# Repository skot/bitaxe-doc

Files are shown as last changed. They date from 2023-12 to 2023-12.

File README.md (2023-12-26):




# Bitaxe Documentation

This Documentation will focus on document everything that is related with the Bitaxe project.

Contributing to this Github repository is highly anticipated and will be done via Github Pull request.
More on how to do that can be found [here](https://docs.github.com/en/pull-requests/collaborating-with-pull-requests/proposing-changes-to-your-work-with-pull-requests/creating-a-pull-request).

---

## 📋 <a name="table">Table of Contents</a>

1. 🤖 [Introduction](#introduction)
2. ⚙️ [How to documentation](#guide)
3. 🔋 [Features](#features)
4. 🎯 [Goals](#goals)
5. 📝 [To-Do's](#todo)
6. 🤸 [Quick Start](#quick-start)
7. 🚀 [More](#more)

---

## <a name="introduction">🤖 Introduction

The Bitaxe is a groundbreaking open-source Bitcoin standalone miner, representing a significant leap in mining technology. At its core, it employs an ASIC chip, a specialized application-specific integrated circuit designed for optimal Bitcoin mining performance. Adding to its innovative features, the Bitaxe is equipped with an ESP32-S3, serving as the brain of the miner and facilitating seamless connectivity to Wi-Fi networks.

One of the key strengths of the Bitaxe lies in its impressive hashrate range, boasting speeds between 250-500 gigahashes per second (Gh/s) while just using up to 15 watts. This high level of computational power allows for efficient and competitive Bitcoin mining, contributing to the overall security and decentralization of the network.

With its open-source nature, the Bitaxe not only provides cutting-edge mining capabilities but also encourages transparency and collaboration within the cryptocurrency community. This unique combination of advanced hardware, open-source philosophy, and substantial hashrate positions the Bitaxe as a noteworthy player in the world of Bitcoin mining.



---

## <a name="guide">⚙️ How to guide through this documentation

This project is divided into three separate parts.
Each of these parts will have it's own `README.md`

To find yourself in the correct Documentation about a specific model you want to build or get to know more about take a look in the [BitaxeMAX (BM1397)](/BitaxeMAX/), [BitaxeUltra (BM1366)](/BitaxeUltra/) and [BitaxeHex](/BitaxeHEX/) section.

In the selected section you will also find an `assembly.md` and a `building.md` these files will give you a general understanding of whats needed to build your own PCB and how to assemble it later on.

---

## <a name="features">🔋 Features

- <b>ESP32-S3-WROOM-1</b> wifi microcontroller on board
- <b>Bitmain ASIC</b> application-specific integrated circuit
- <b>FOSS</b>

---

## <a name="goals">🎯 Goals

- <b>Standalone:</b> can mine directly to your pool over Wi-Fi. No external computer needed.
- <b>Embedded:</b> low cost, low maintenance, high availability, high reliability, low power consumption.
- <b>ASIC:</b> based on the very efficient BM1366 from Bitmain.
- <b>Open Source:</b> everything of this project is available on Github.

---

## <a name="todo">📝 To-Do's

- [ ] Hex
- [ ] 201+ TP reading's
- [ ] Section for Public Pool

---

## <a name="quick-start">🤸 Quick Start

The Bitaxe-instructions.pdf file contains a general instruction set.

[Setup Instruction Guide](/Bitaxe-Instructions.pdf)

---

## <a name="more">🚀 More

### 1. Software

- The [ESP-Miner](https://github.com/skot/ESP-Miner) firmware used for the BM1397-based bitaxe has been adapted for the BM1366 and the current main branch can support both.
- There is still work to be done on reverse engineering the BM1366 register map. If you can help, get in touch!

### 2. Hardware

- The [Bitaxe](https://github.com/skot/bitaxe) repository hosts all hardware requirements and manufacturing files to build your own Bitaxe

### 3.💸Vendors

- There are currently two official OSMU vendors:

  - [OSMU](https://opensourceminer.com)
  - [JABIT](https://www.jabitaxe.com)

- And 5 other selling Bitaxe aswell:
  - [D-Central](https://d-central.tech)
  - [RGZen](https://www.rgzen.com/index.php)
  - [Altair](https://altairtech.io/product/bitaxe/)
  - [BitcoinMerch](https://bitcoinmerch.com/de/products/bitcoin-merch%C2%AE-bitaxe-1366-solo-bitcoin-miner-up-to-500gh-s)
  - [Thesolomining](https://www.thesolomining.co/bitaxe)

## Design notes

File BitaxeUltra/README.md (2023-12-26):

# BitaxeUltra

The Bitaxe Ultra is the currently most used model.

---

## 📋 <a name="table">Table of Contents</a>

1. 🤖 [Introduction](#introduction)
2. 🛠️ [Hardware](#hardware)
3. ⚙️ [Configure the BitaxeUltra](#guide)
4. 🔋 [Features](#features)
5. 🎯 [Goals](#goals)
6. 📝 [To-Do's](#todo)

---

## <a name="introduction">🤖 What is this?

The Bitaxe Ultra is a groundbreaking open-source Bitcoin standalone miner, representing a significant leap in mining technology. At its core, it employs an ASIC BM1366 chip, a specialized application-specific integrated circuit designed for optimal Bitcoin mining performance. Adding to its innovative features, the Bitaxe M Ultra is equipped with an ESP32-S3, serving as the brain of the miner and facilitating seamless connectivity to Wi-Fi networks.

One of the key strengths of the Bitaxe Ultra lies in its impressive hashrate range, boasting speeds between 300-600 gigahashes per second (Gh/s) while just using up to 15 watts. This high level of computational power allows for efficient and competitive Bitcoin mining, especially compared to the previous version the BitaxeUltra, contributing to the overall security and decentralization of the network.

With its open-source nature, the Bitaxe Ultra not only provides cutting-edge mining capabilities but also encourages transparency and collaboration within the cryptocurrency community. This unique combination of advanced hardware, open-source philosophy, and substantial hashrate positions the Bitaxe Ultra as a noteworthy player in the world of Bitcoin mining.

## <a name="hardware">🛠️ Hardware

- [BM1366 from NBTC on AliExpress](https://www.aliexpress.us/item/3256804709142138.html). I got the "AG" variant. Not really sure what the difference is.
- [40x40mm heatsink and 5V fan](https://www.aliexpress.com/item/2251832861666365.html) from a random AliExpress seller. At least half of these arrived broken in some way. But they are cheap and the working ones do keep the BM1387's nice and cool when used with some thermal compound.
  - Swap this fan with the [Noctua NF-A4x10](https://noctua.at/en/products/fan/nf-a4x10-pwm) 5V 4-Pin fan for a much more pleasant experience.
- Supports 0.91" SSD1306-based I2C OLED Module. [Example Amazon seller](https://www.amazon.com/gp/product/B08ZY4YBHL)
- The BM1366 serial port is 1.8V. These pins are broken out, but the main idea is to communicate with the BM1366 from the ESP32
- Level shifters to interface the 1.8V BM1366 with the 3.3V ESP32. These pins are also broken out.
- [KiCad 7](https://www.kicad.org) design files
- All of the parts on the board are listed in the KiCad BOM

The BM1366 is a undocumented SHA256 mining ASIC from Bitmain. It's mostly used in the Antminer S19XP.
Bitmain claims the BM1366 has 0.021J/GH efficiency

The BM1366 has a different footprint and pinout from the BM1397 and BM1387 in previous bitaxe.
The BM1366 appears to roll more than just the nonce on the chip. This is great news, because it allows much longer serial chains of ASICs and new work doesn't need to be sent as often.

---

## <a name="guide">⚙️ Guide

The BitaxeUltra can be either purchased as a fully functional standalone Bitcoin miner, or you can build your own with the following guides in [Assembly](assembly.md) and [Building](building.md). Building this on your own will take much longer and requires a high skillset of SMD soldering and handling.

## Building

1. Building and Assembliy

   - These two readme files will guide you throu the process of whats needed to build and order your own BitaxeUltra board.
     - [Assembly-readme](assembly.md)
     - [Building-readme](building.md)
   - There are some Videos and Streams about how to Assembly a Bitaxe from scratch from some YouTubers such as [D-Central](https://www.youtube.com/@DCentralTech) and [WantClue](https://www.youtube.com/@WantClue)

2. Schematics

   - Futhermore for a more detailed view into the Schematics of the BitaxeUltra board you can view [BitaxeUltraSchematic](/BitaxeUltra/BitaxeUltra-schematic.pdf).

3. Manufacturing Files
   - In the [Manufacturing_Files_Folder](Manufacturing_Files) you will find all the necessary files to create your own PCB from Gerber files and the BOM(Build of Matierial) a list of all the components needed to build the BitaxeUltra

---

## Software

1. Building your Software

   - You can build your own binary files from the source code. For more details follow this [Build-Guide](/BitaxeMAX/software.md).

2. Using a prebuild

   - Every Bitaxe is controlled by the open source available [ESP-Miner](https://github.com/skot/ESP-Miner) software. It features a WebUi for user friendly usage and controlablility.
   - In this repository you will also find a [releases](https://github.com/skot/ESP-Miner/releases) page that will contain prebuild binary files to flash to your Bitaxe using the [Bitaxetool](https://github.com/johnny9/bitaxetool) created by [johnny9](https://github.com/johnny9).

3. Flashing Process
   - The [ESP-Miner](https://github.com/skot/ESP-Miner) Software can be flashed via a USB cable onto the Bitaxe. Therefore you need to follow the initial Guide in the repository.

## <a name="features">🔋 Features

This documentation features the following:

- An interactive build of material, to allow you to assemble the Bitaxe quicker. [iBOM](/BitaxeUltra/Manufacturing_Files/ibom.html)
- The Bitaxe Ultra features a BM1366 ASIC chip (usually the AG variant)

## <a name="goals">🎯 Goals

- [x] The most efficient open source miner 19J/TH
- [ ] Make the mining industry a bit more open source

## <a name="todo">📝 To-Do's

- [ ] TP Readings
- [ ] Freq / Voltage area

### <a name="pictures">🖼️ Pictures

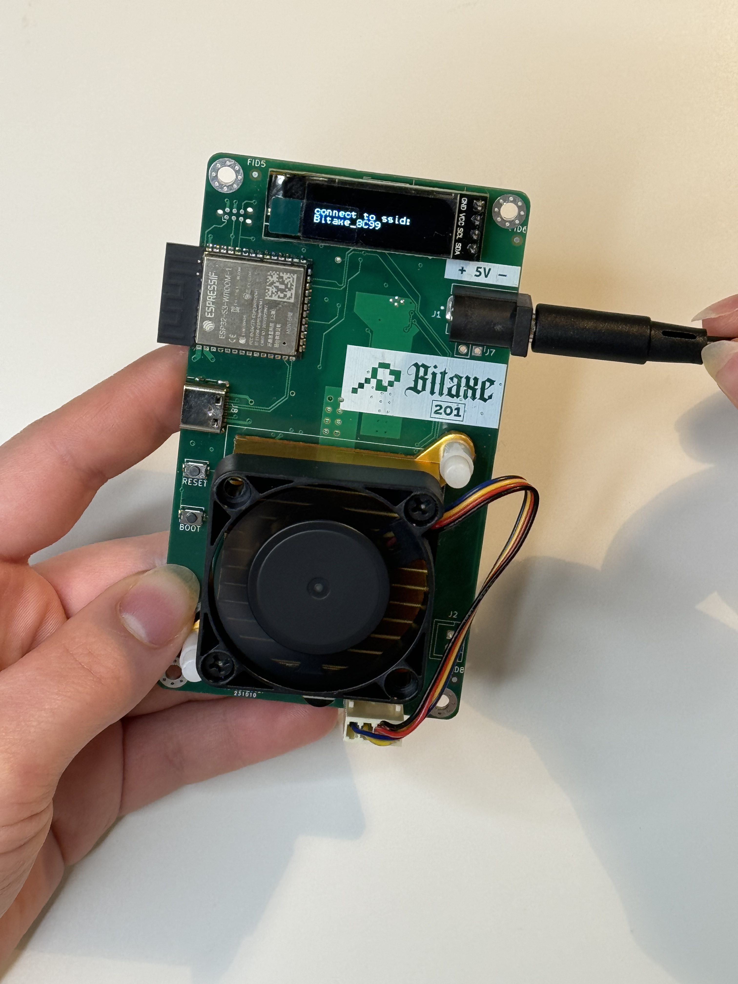
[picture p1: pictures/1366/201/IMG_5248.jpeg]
BitaxeUltra


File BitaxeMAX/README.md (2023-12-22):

# BitaxeMax(1397)

The BitaxeMax is the world's first open source Bitcoin Miner which uses the ASIC BM1397 chip to achieve astonishing results.

## 📋 <a name="table">Table of Contents</a>

1. 🤖 [Introduction](#introduction)
2. 🛠️ [Hardware](#hardware)
3. ⚙️ [Guide the BitaxeMAX](#guide)
4. 🔋 [Features](#features)
5. 🎯 [Goals](#goals)
6. 📝 [To-Do's](#todo)
7. 🖼️ [Pictures](#pictures)

---

## <a name="introduction"> What is this?

The Bitaxe Max is a groundbreaking open-source Bitcoin standalone miner, representing a significant leap in mining technology. At its core, it employs an ASIC 1397 chip, a specialized application-specific integrated circuit designed for optimal Bitcoin mining performance. Adding to its innovative features, the Bitaxe Max is equipped with an ESP32-S3, serving as the brain of the miner and facilitating seamless connectivity to Wi-Fi networks.

One of the key strengths of the Bitaxe Max lies in its impressive hashrate range, boasting speeds between 250-450 gigahashes per second (Gh/s) while just using up to 15 watts. This high level of computational power allows for efficient and competitive Bitcoin mining, contributing to the overall security and decentralization of the network.

With its open-source nature, the Bitaxe Max not only provides cutting-edge mining capabilities but also encourages transparency and collaboration within the cryptocurrency community. This unique combination of advanced hardware, open-source philosophy, and substantial hashrate positions the Bitaxe Max as a noteworthy player in the world of Bitcoin mining.

---

## <a name="hardware">🛠️ Hardware

The Bitaxe in general uses an <b>ESP32-S3-WROOM-1</b> to operate the whole device. On there is a specificaly written Software that serves as the Brain of this operation. It does the handleing of the job functions to the ASIC and it allows to connect to the Internet over Wi-Fi.

- The BM1397 is a undocumented SHA256 mining ASIC from Bitmain. It's mostly used in the Antminer S17 and T17
- Bitmain claims the BM1397 has 0.03J/GH efficiency
- The BM1397 is available (new) for around $20 each and (used) for around $6 ea in small quantities.
- Choose your BM1397 version: [Guide here](https://d-central.tech/bm1397-ad-ag-ah-ai-antminer-17-series-chip-replacement-guide/)
- The BM1397 has the same footprint as the BM1387, but a very different pinout.
  - It also has two "Modes" that change some of the signal pins around to make chaining easy
- The BM1397 is driven by an undocumented protocol over UART. Baudrate is 115200bps by default but can go up to 6Mbps in order to provide mining jobs quickly enough to the ASIC daisy-chain.

---

# <a name="guide">⚙️ Guide

The BitaxeMAX can be either purchased as a fully functional standalone Bitcoin miner, or you can build your own with the following guides in [Assembly](assembly.md) and [Building](building.md). Building this on your own will take much longer and requires a high skillset of SMD soldering and handling.

## Building

1. Building and Assembliy

   - These two readme files will guide you throu the process of whats needed to build and order your own BitaxeMAX board.
     - [Assembly-readme](assembly.md)
     - [Building-readme](building.md)
   - There are some Videos and Streams about how to Assembly a Bitaxe from scratch from some YouTubers such as [D-Central](https://www.youtube.com/@DCentralTech) and [WantClue](https://www.youtube.com/@WantClue)

2. Schematics

   - Futhermore for a more detailed view into the Schematics of the BitaxeMAX board you can view [BitaxeMaxSchematic](bitaxeMax_schematic.pdf).

3. Manufacturing Files
   - In the [Manufacturing_Files_Folder](Manufacturing_Files) you will find all the necessary files to create your own PCB from Gerber files and the BOM(Build of Matierial) a list of all the components needed to build the BitaxeMAX

---

## Software

1. Building your Software

   - You can build your own binary files from the source code. For more details follow this [Build-Guide](/BitaxeMAX/software.md).

2. Using a prebuild

   - Every Bitaxe is controlled by the open source available [ESP-Miner](https://github.com/skot/ESP-Miner) software. It features a WebUi for user friendly usage and controlablility.
   - In this repository you will also find a [releases](https://github.com/skot/ESP-Miner/releases) page that will contain prebuild binary files to flash to your Bitaxe using the [Bitaxetool](https://github.com/johnny9/bitaxetool) created by [johnny9](https://github.com/johnny9).

3. Flashing Process
   - The [ESP-Miner](https://github.com/skot/ESP-Miner) Software can be flashed via a USB cable onto the Bitaxe. Therefore you need to follow the initial Guide in the repository.

---

## <a name="features">🔋 Features

- **ESP32-S3-WROOM-1** wifi microcontroller on board
- **TI TPS40305** buck regulator steps down the 5V input to power the BM1397
- **Maxim DS4432U+** current DAC digitally adjusts the BM1397 core voltage from 0.04V to 2.4V
- **TI INA260** power meter measures the input voltage and current of the miner
- **Microchip EMC2101** measures the BM1397 internal diode temperature. Also PWM controls the fan and monitors tach output.
- Two **sweet** RGB status LEDs

---

## <a name="goals">🎯 Goals

- [x] Standalone Miner
- [x] Reverse Engineering the Bitmain BM1397
- [ ] Tweak the J/GH efficiency and figure out how far we can go

---

## <a name="todo">📝 To-Do's

Any open issues will be listed here.

### <a name="pictures">🖼️ Pictures

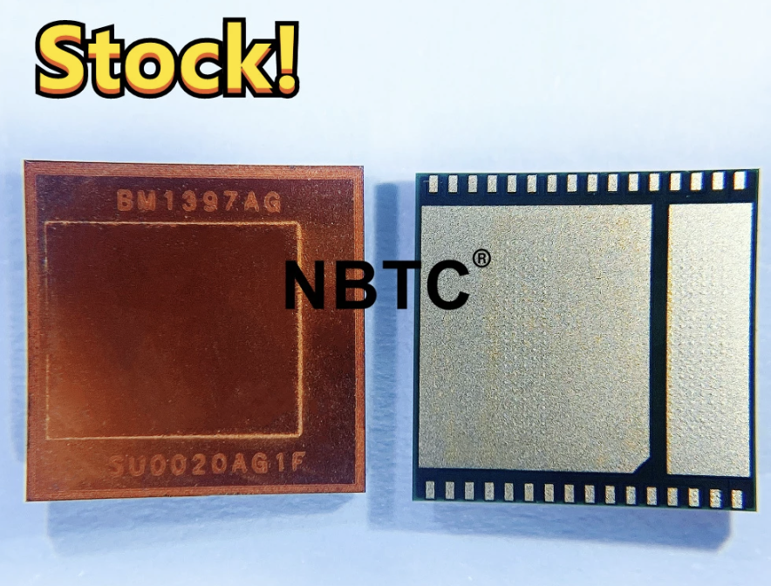
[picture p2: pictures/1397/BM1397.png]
BM1397

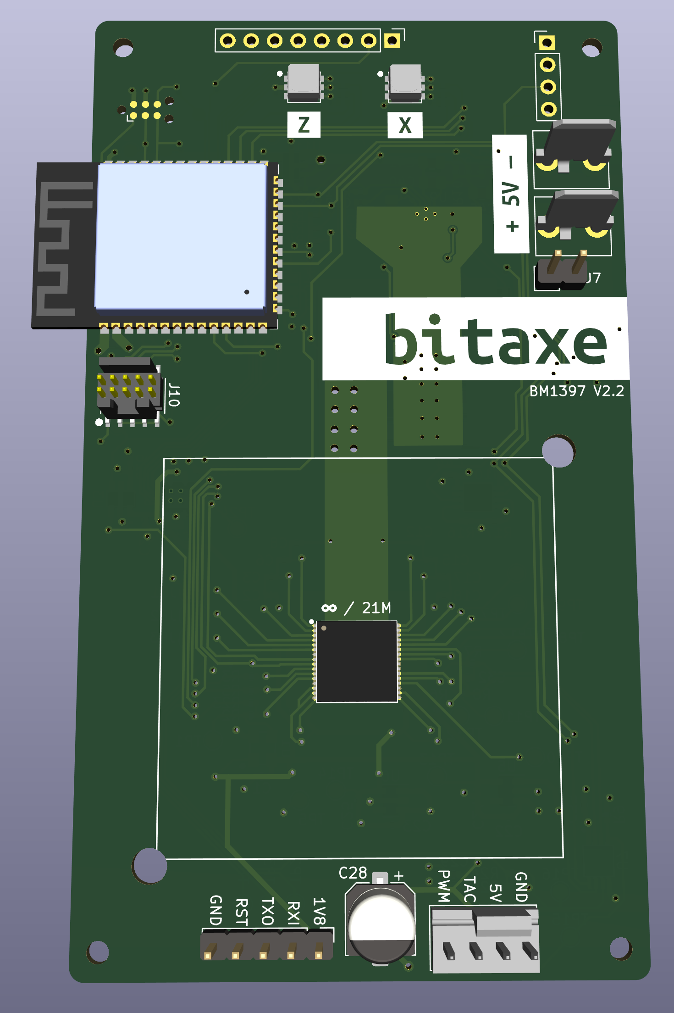
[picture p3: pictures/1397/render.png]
bitaxeMAX


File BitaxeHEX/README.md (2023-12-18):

# BitaxeHex

The BitaxeHex is currently a prototype concept and is hardly under development.

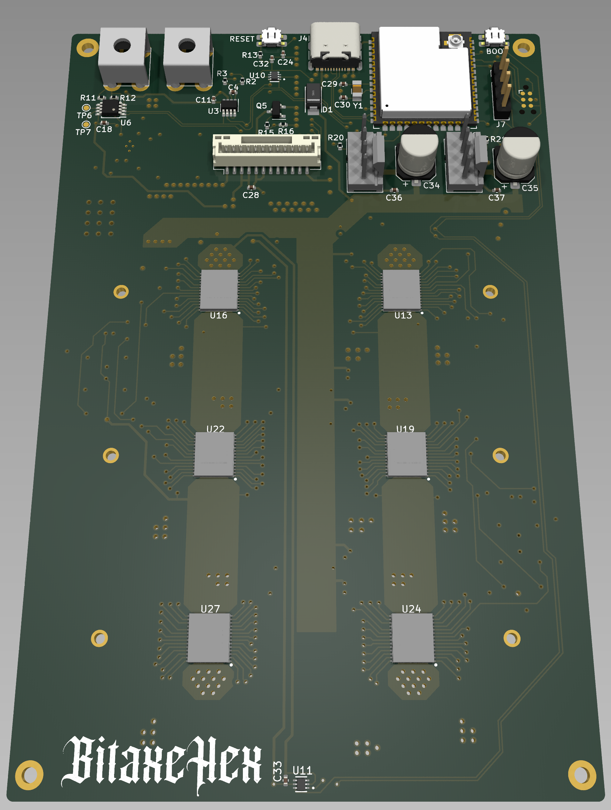
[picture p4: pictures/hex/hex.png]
HEX


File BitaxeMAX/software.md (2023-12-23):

# How to build your own software from source

This guide will focus on the process for Windows Users. If MacOS/Linux will follow you will find them in there section:

## 📋 <a name="table">Table of Contents</a>

1. 💻 [Windows](#windows)
2. 🍏 [MacOS](#mac)
3. 🐧 [Linux](#linux)

## Requirements

- ESP IDF
- Espressif Tool VSCode
- This firmware is designed to run a Bitaxe v2+

## <a name="windows"> 💻 Windows

### Installation

- You need to install the Espressif tool from [here](https://docs.espressif.com/projects/esp-idf/en/latest/esp32/get-started/windows-setup.html).
  On this page you will find a Get Started guide for installing this onto your machine.

      -   After you have installed the espressif tool onto your machine you need to install Visual Studio Code, link [here](https://code.visualstudio.com/).

          -   The next step is to install the `Espressif IDF` Extention in VSCode
          -   on the left sidebar click on the Extensions Tab and search for Espressif IDF and install the latest version

### Clone repository

Clone the [ESP-Miner](https://github.com/skot/ESP-Miner) repository and open it in VSCode.

### Configuration

After you have installed everything we need to configure the Espressif Tool.

View --> ESP-IDF: Device Configuration --> Device Target --> ESP-Miner --> esp32s3 --> ESP-S3 via USB Bridge

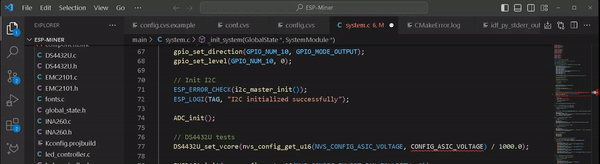
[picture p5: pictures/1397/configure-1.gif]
configure-1


### Build

Now we need to open an ESP-IDF terminal and cd into the `/main/http_server/axe-os/` folder and build the WebUI first and then we can build the firmware.
use

```linux
nmp run build
```

after that use this command:

```linux
idf.py build
```

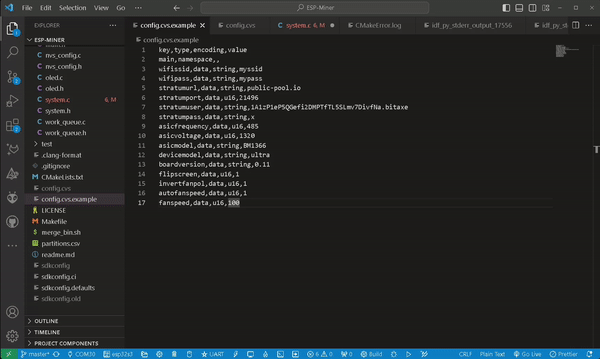
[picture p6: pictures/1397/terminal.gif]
terminal


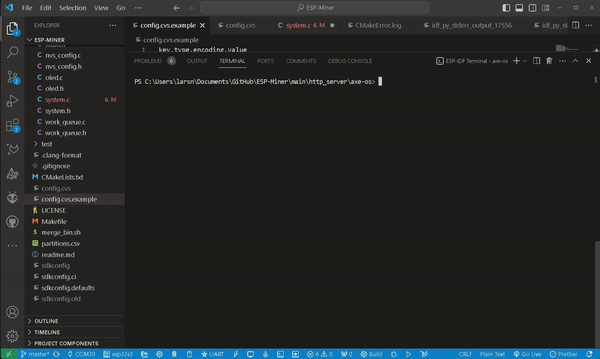
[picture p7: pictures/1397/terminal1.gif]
terminal2


The `idf.py` command needs to be executed in the ESP-Miner home directory so keep in mind to cd back into it after you build the WebUI.

After that you will find a `build` directory and in there you will find the `www.bin`and the `esp-miner.bin` files. These can be used to upload to your Bitaxe.

## <a name="mac"> 🍏 MacOS

## <a name="linux"> 🐧 Linux

### Step 1. Installation

To compile using ESP-IDF, you need to get the following packages. The command to run depends on which distribution of Linux you are using:

Ubuntu and Debian:

```Linux
sudo apt-get install git wget flex bison gperf python3 python3-pip python3-venv cmake ninja-build ccache libffi-dev libssl-dev dfu-util libusb-1.0-0
```

CentOS 7 & 8:

```Linux
sudo yum -y update && sudo yum install git wget flex bison gperf python3 cmake ninja-build ccache dfu-util libusbx
```

Arch:

```Linux
sudo pacman -S --needed gcc git make flex bison gperf python cmake ninja ccache dfu-util libusb
```

### Step 2. Get ESP-IDF

To build applications for the ESP32, you need the software libraries provided by Espressif in [ESP-IDF repository](https://github.com/espressif/esp-idf).

To get ESP-IDF, navigate to your installation directory and clone the repository with `git clone`, following instructions below specific to your operating system.

Open Terminal, and run the following commands:

```Linux
mkdir -p ~/esp
cd ~/esp
git clone --recursive https://github.com/espressif/esp-idf.git
```

ESP-IDF is downloaded into `~/esp/esp-idf`.

### Step 3. Set up the Tools

Aside from the ESP-IDF, you also need to install the tools used by ESP-IDF, such as the compiler, debugger, Python packages, etc, for projects supporting ESP32.

```Linux
cd ~/esp/esp-idf
./install.sh esp32s3
```

### Step 4. Setup Environments Variables

The installed tools are not yet added to the PATH environment variable. To make the tools usable from the command line, some environment variables must be set. ESP-IDF provides another script which does that.

In the terminal where you are going to use ESP-IDF, run:

```linux
. $HOME/esp/esp-idf/export.sh
```

**Note the space between the leading dot and the path!**

If you plan to use esp-idf frequently, you can create an alias for executing `export.sh`:

1. Copy and paste the following command to your shell's profile (`.profile`, `.bashrc`, `.zprofile`, etc.)

```linux
alias get_idf='. $HOME/esp/esp-idf/export.sh'
```

2. Refresh the configuration by restarting the terminal session or by running `source [path to profile]`, for example, `source ~/.bashrc`.

Now you can run `get_idf` to set up or refresh the esp-idf environment in any terminal session.

### Clone repository

Clone the [ESP-Miner](https://github.com/skot/ESP-Miner) repository and open it in VSCode.

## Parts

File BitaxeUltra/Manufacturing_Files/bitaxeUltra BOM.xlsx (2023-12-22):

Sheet: BOM
Qty | Ref Des | Value | DK | PARTNO | DNP
9 | C1, C7, C9, C19, C20, C29, C33, C42, C52 | 0.1uF | 1292-1639-1-ND | 0402X104K100CT
23 | C2, C3, C4, C5, C6, C8, C10, C11, C12, C14, C15, C16, C17, C18, C21, C22, C23, C24, C25, C27, C35, C44, C49 | 1uF | 587-5514-1-ND | EMK105BJ105MV-F
1 | C13 | 330uF | 718-1028-1-ND | 293D337X9010E2TE3
1 | C28 | 220uF | 732-8422-1-ND | 865080345012
2 | C30, C31 | 6.8pF | 399-C0402C689C5GAC7867CT-ND | C0402C689C5GAC7867
3 | C34, C36, C37 | 47uF | 490-6539-1-ND | GRM32ER61C476KE15L
1 | C38 | 1uF | 1276-6471-1-ND | CL21B105KOFNNNG
1 | C39 | 3.3nF | 1276-1552-1-ND | CL05B332KB5NNNC
1 | C40 | 180pF | 311-1114-1-ND | CC0805JRNPO9BN181
1 | C41 | 1.5nF | 311-1128-1-ND | CC0805KRX7R9BB152
2 | C43, C51 | 10uF | 1276-1096-1-ND | CL21A106KOQNNNE
1 | C45 | 470pF | 1292-1580-1-ND | 0805B471K500CT
1 | C46 | 220uF | P16200CT-ND | 2R5TPE220MAFB
1 | C47 | 100uF | 445-6008-1-ND | C3216X5R0J107M160AB
1 | D1 | SS310 | SK310A-LTPMSCT-ND | SK310A-LTP
1 | J1 | 54-00164 | 839-54-00164CT-ND | 54-00164
1 | J2 | Conn_01x02 | 455-B2B-XH-A-ND | B2B-XH-A
1 | J4 | Conn_01x04 | WM4330-ND | 0470531000
1 | J8 | USB_C_Receptacle_USB2.0 | 2073-USB4105-GF-ACT-ND | USB4105-GF-A
1 | L1 | 150nH | 513-1568-1-ND | FP1005R1-R15-R
2 | Q1, Q2 | CSD17311Q5 | 296-27625-1-ND | CSD17311Q5
1 | Q4 | 2N7002K | 2N7002KWCT-ND | 2N7002KW
5 | R1, R4, R6, R7, R9 | 10k | 311-10KJRCT-ND | RC0402JR-0710KL
1 | R2 | 5.6k | 13-RC0402FR-135K6LCT-ND | RC0402FR-135K6L
2 | R3, R5 | 5.1k | RMCF0402JT5K10CT-ND | RMCF0402JT5K10
1 | R8 | 1M | 311-1.00MLRCT-ND | RC0402FR-071ML
1 | R10 | 3.83k | 311-3.83KLRCT-ND | RC0402FR-073K83L
1 | R11 | 100k | 311-100KJRCT-ND | RC0402JR-07100KL | DNP
1 | R12 | 4.12k | RMCF0402FT4K12CT-ND | RMCF0402FT4K12
1 | R13 | 1.33k | 311-1.33KLRCT-ND | RC0402FR-071K33L
1 | R14 | 4.99k | 311-4.99KLRCT-ND | RC0402FR-074K99L
1 | R15 | 3.32k | 311-3.32KLRCT-ND | RC0402FR-073K32L
1 | R16 | 80.6k | 311-80.6KLRCT-ND | RC0402FR-0780K6L
2 | SW1, SW2 | GT-TC029B-H025-L1N | 2449-CS1213AGF260CT-ND | CS1213AGF260
1 | U1 | 25MHz | 1908-O250-JO32-B-1V3-1-T1-LFCT-ND | O 25,0-JO32-B-1V3-1-T1-LF
1 | U2 | TXB0104RGYR | 296-21930-1-ND | TXB0104RGYR
1 | U5 | MCP1824T-1802E | MCP1824T-1802E/OTCT-ND | MCP1824T-1802E/OT
1 | U6 | MCP1824T-0802E | MCP1824T-0802E/OTCT-ND | MCP1824T-0802E/OT
1 | U7 | EMC2101 | EMC2101-R-ACZL-CT-ND | EMC2101-R-ACZL-TR
1 | U8 | INA260 | 296-45218-5-ND | INA260AIPW
1 | U9 | TPS40305 | 296-37445-1-ND | TPS40305DRCR
1 | U10 | DS4432U+ | DS4432U+-ND | DS4432U+
1 | U11 | RT9080-33GJ5 | 1028-1509-1-ND | RT9080-33GJ5
1 | U12 | ESP32-S3-WROOM-1 | 1965-ESP32-S3-WROOM-1-N16R8CT-ND | ESP32-S3-WROOM-1-N16R8
1 | U14 | BM1366_mode1
1 | Y1 | 32.768kHz | 728-1074-1-ND | SC32S-7PF20PPM

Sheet: DK Order
Qty | Ref Des | DK
9 | C1, C7, C9, C19, C20, C29, C33, C42, C52 | 1292-1639-1-ND
23 | C2, C3, C4, C5, C6, C8, C10, C11, C12, C14, C15, C16, C17, C18, C21, C22, C23, C24, C25, C27, C35, C44, C49 | 587-5514-1-ND
1 | C13 | 718-1028-1-ND
1 | C28 | 732-8422-1-ND
2 | C30, C31 | 399-C0402C689C5GAC7867CT-ND
3 | C34, C36, C37 | 490-6539-1-ND
1 | C38 | 1276-6471-1-ND
1 | C39 | 1276-1552-1-ND
1 | C40 | 311-1114-1-ND
1 | C41 | 311-1128-1-ND
2 | C43, C51 | 1276-1096-1-ND
1 | C45 | 1292-1580-1-ND
1 | C46 | P16200CT-ND
1 | C47 | 445-6008-1-ND
1 | D1 | SK310A-LTPMSCT-ND
1 | J1 | 839-54-00164CT-ND
1 | J2 | 455-B2B-XH-A-ND
1 | J4 | WM4330-ND
1 | J8 | 2073-USB4105-GF-ACT-ND
1 | L1 | 513-1568-1-ND
2 | Q1, Q2 | 296-27625-1-ND
1 | Q4 | 2N7002KWCT-ND
5 | R1, R4, R6, R7, R9 | 311-10KJRCT-ND
1 | R2 | 13-RC0402FR-135K6LCT-ND
2 | R3, R5 | RMCF0402JT5K10CT-ND
1 | R8 | 311-1.00MLRCT-ND
1 | R10 | 311-3.83KLRCT-ND
1 | R12 | RMCF0402FT4K12CT-ND
1 | R13 | 311-1.33KLRCT-ND
1 | R14 | 311-4.99KLRCT-ND
1 | R15 | 311-3.32KLRCT-ND
1 | R16 | 311-80.6KLRCT-ND
2 | SW1, SW2 | 2449-CS1213AGF260CT-ND
1 | U1 | 1908-O250-JO32-B-1V3-1-T1-LFCT-ND
1 | U2 | 296-21930-1-ND
1 | U5 | MCP1824T-1802E/OTCT-ND
1 | U6 | MCP1824T-0802E/OTCT-ND
1 | U7 | EMC2101-R-ACZL-CT-ND
1 | U8 | 296-45218-5-ND
1 | U9 | 296-37445-1-ND
1 | U10 | DS4432U+-ND
1 | U11 | 1028-1509-1-ND
1 | U12 | 1965-ESP32-S3-WROOM-1-N16R8CT-ND
1 | U14
1 | Y1 | 728-1074-1-ND

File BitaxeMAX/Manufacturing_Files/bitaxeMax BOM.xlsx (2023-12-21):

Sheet: BOM
Qty | Ref Des | Value | DK | PARTNO | DNP
13 | C1, C7, C9, C19, C20, C21, C22, C23, C26, C29, C33, C42, C52 | 0.1uF | 1292-1639-1-ND | 0402X104K100CT
21 | C2, C3, C4, C5, C6, C8, C10, C11, C12, C14, C15, C16, C17, C18, C24, C25, C27, C35, C44, C49, C50 | 1uF | 587-5514-1-ND | EMK105BJ105MV-F
1 | C13 | 330uF | 718-1028-1-ND | 293D337X9010E2TE3
1 | C28 | 220uF | 732-8422-1-ND | 865080345012
2 | C30, C31 | 6.8pF | 399-C0402C689C5GAC7867CT-ND | C0402C689C5GAC7867
1 | C32 | 470pF | 1276-1566-1-ND | CL05B471KB5NNNC
3 | C34, C36, C37 | 47uF | 490-6539-1-ND | GRM32ER61C476KE15L
1 | C38 | 1uF | 1276-6471-1-ND | CL21B105KOFNNNG
1 | C39 | 3.3nF | 1276-1552-1-ND | CL05B332KB5NNNC
1 | C40 | 180pF | 311-1114-1-ND | CC0805JRNPO9BN181
1 | C41 | 1.5nF | 311-1128-1-ND | CC0805KRX7R9BB152
2 | C43, C51 | 10uF | 1276-1096-1-ND | CL21A106KOQNNNE
1 | C45 | 470pF | 1292-1580-1-ND | 0805B471K500CT
1 | C46 | 220uF | P16200CT-ND | 2R5TPE220MAFB
1 | C47 | 100uF | 445-6008-1-ND | C3216X5R0J107M160AB
4 | H1, H2, H3, H4 | AlignmentHole |  | https://www.amazon.com/dp/B07MDFS1YS | T
2 | H5, H6 | MountingHole |  |  | T
1 | IC1 | BM1397_mode1 |  |  | T
2 | J1, J2 | Conn_01x01 | A100886CT-ND | 63862-1
1 | J3 | Conn_01x05 |  |  | T
1 | J4 | Conn_01x04 | WM4330-ND | 0470531000
1 | J5 | TC2030-IDC |  |  | T
1 | J6 | Conn_01x08 |  |  | T
1 | J7 | Conn_01x02 |  |  | T
1 | J9 | Conn_01x04 |  |  | T
1 | J10 | FTSH-105-01-F-DV-K | SAM8796-ND | FTSH-105-01-F-DV-K
2 | JP1, JP2 | SolderJumper_2_Open |  |  | T
1 | JP3 | SolderJumper_2_Bridged |  |  | T
1 | JP4 | JTAG Source |  |  | T
1 | L1 | 150nH | 513-1568-1-ND | FP1005R1-R15-R
2 | Q1, Q2 | CSD17311Q5 | 296-27625-1-ND | CSD17311Q5
3 | R1, R18, R19 | 1k | YAG2306CT-ND |  | T
4 | R2, R3, R5, R23 | 0 | RMCF0402ZT0R00CT-ND | RMCF0402ZT0R00
6 | R4, R6, R9, R20, R24, R36 | 10k | 311-10KJRCT-ND | RC0402JR-0710KL
2 | R7, R8 | 100 | RMCF0402FT100RCT-ND | RMCF0402FT100R
1 | R10 | 3.83k | 311-3.83KLRCT-ND | RC0402FR-073K83L
1 | R11 | 100k | 311-100KJRCT-ND | RC0402JR-07100KL
1 | R12 | 4.12k | RMCF0402FT4K12CT-ND | RMCF0402FT4K12
1 | R13 | 1.33k | 311-1.33KLRCT-ND | RC0402FR-071K33L
1 | R14 | 4.99k | 311-4.99KLRCT-ND | RC0402FR-074K99L
1 | R15 | 3.32k | 311-3.32KLRCT-ND | RC0402FR-073K32L
1 | R16 | 80k | 311-80.6KLRCT-ND | RC0402FR-0780K6L
1 | R17 | DNP |  |  | T
2 | R21, R22 | 60.4 | 311-60.4LRCT-ND | RC0402FR-0760R4L
1 | R25 | 19.1k | YAG3027CT-ND | RC0402FR-0719R1L
2 | R26, R27 | 100 | RMCF0402FT100RCT-ND | RMCF0402FT100R
2 | R28, R29 | 261 | YAG3078CT-ND | RC0402FR-07261RL
31 | TP1, TP2, TP3, TP4, TP5, TP6, TP7, TP8, TP9, TP10, TP11, TP12, TP13, TP14, TP15, TP16, TP17, TP18, TP19, TP21, TP22, TP23, TP24, TP25, TP26, TP27, TP28, TP29, TP30, TP31, TP32 | TestPoint |  |  | T
1 | U1 | 25MHz | 1908-O250-JO32-B-1V3-1-T1-LFCT-ND | O 25,0-JO32-B-1V3-1-T1-LF
1 | U2 | TXB0104RGYR | 296-21930-1-ND | TXB0104RGYR
1 | U3 | SN74AXC1T45DBVR | 296-47598-1-ND | SN74AXC1T45DBVR
2 | U4, U13 | CLX6E-FKC | CLX6E-FKC-CH1M1D1BB7C3D3CT-ND | CLX6E-FKC-CH1M1D1BB7C3D3
1 | U5 | MCP1824T-1802E | MCP1824T-1802E/OTCT-ND | MCP1824T-1802E/OT
1 | U6 | MCP1824T-0802E | MCP1824T-0802E/OTCT-ND | MCP1824T-0802E/OT
1 | U7 | EMC2101 | EMC2101-R-ACZL-CT-ND | EMC2101-R-ACZL-TR
1 | U8 | INA260 | 296-47777-1-ND | INA260AIPWR
1 | U9 | TPS40305 | 296-37445-1-ND | TPS40305DRCR
1 | U10 | DS4432U+ | DS4432U+-ND | DS4432U+
1 | U11 | RT9080-33GJ5 | 1028-1509-1-ND | RT9080-33GJ5
1 | U12 | ESP32-S3-WROOM-1 | 1965-ESP32-S3-WROOM-1-N16R8CT-ND | ESP32-S3-WROOM-1-N16R8
1 | Y1 | 32.768kHz | 728-1074-1-ND | SC32S-7PF20PPM

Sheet: DK Order
Qty | Ref Des | DK
13 | C1, C7, C9, C19, C20, C21, C22, C23, C26, C29, C33, C42, C52 | 1292-1639-1-ND
21 | C2, C3, C4, C5, C6, C8, C10, C11, C12, C14, C15, C16, C17, C18, C24, C25, C27, C35, C44, C49, C50 | 587-5514-1-ND
1 | C13 | 718-1028-1-ND
1 | C28 | 732-8422-1-ND
2 | C30, C31 | 399-C0402C689C5GAC7867CT-ND
1 | C32 | 1276-1566-1-ND
3 | C34, C36, C37 | 490-6539-1-ND
1 | C38 | 1276-6471-1-ND
1 | C39 | 1276-1552-1-ND
1 | C40 | 311-1114-1-ND
1 | C41 | 311-1128-1-ND
2 | C43, C51 | 1276-1096-1-ND
1 | C45 | 1292-1580-1-ND
1 | C46 | P16200CT-ND
1 | C47 | 445-6008-1-ND
2 | J1, J2 | A100886CT-ND
1 | J4 | WM4330-ND
1 | J10 | SAM8796-ND
1 | L1 | 513-1568-1-ND
2 | Q1, Q2 | 296-27625-1-ND
4 | R2, R3, R5, R23 | RMCF0402ZT0R00CT-ND
6 | R4, R6, R9, R20, R24, R36 | 311-10KJRCT-ND
2 | R7, R8 | RMCF0402FT100RCT-ND
1 | R10 | 311-3.83KLRCT-ND
1 | R11 | 311-100KJRCT-ND
1 | R12 | RMCF0402FT4K12CT-ND
1 | R13 | 311-1.33KLRCT-ND
1 | R14 | 311-4.99KLRCT-ND
1 | R15 | 311-3.32KLRCT-ND
1 | R16 | 311-80.6KLRCT-ND
2 | R21, R22 | 311-60.4LRCT-ND
1 | R25 | YAG3027CT-ND
2 | R26, R27 | RMCF0402FT100RCT-ND
2 | R28, R29 | YAG3078CT-ND
1 | U1 | 1908-O250-JO32-B-1V3-1-T1-LFCT-ND
1 | U2 | 296-21930-1-ND
1 | U3 | 296-47598-1-ND
2 | U4, U13 | CLX6E-FKC-CH1M1D1BB7C3D3CT-ND
1 | U5 | MCP1824T-1802E/OTCT-ND
1 | U6 | MCP1824T-0802E/OTCT-ND
1 | U7 | EMC2101-R-ACZL-CT-ND
1 | U8 | 296-47777-1-ND
1 | U9 | 296-37445-1-ND
1 | U10 | DS4432U+-ND
1 | U11 | 1028-1509-1-ND
1 | U12 | 1965-ESP32-S3-WROOM-1-N16R8CT-ND
1 | Y1 | 728-1074-1-ND

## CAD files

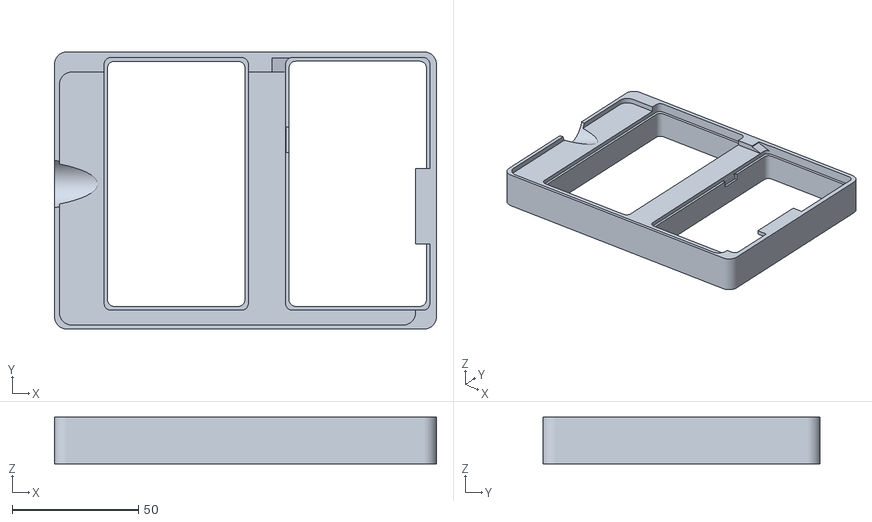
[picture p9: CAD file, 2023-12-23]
BitaxeUltra/Manufacturing_Files/stencil_tool_V3.stl
151.5 x 110.0 x 18.6

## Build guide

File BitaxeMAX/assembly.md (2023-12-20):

# SMD Soldering Guide with Convection Toaster Oven

To achieve successful SMD soldering, follow these steps using a convection toaster oven and the recommended tools.

## Tools and Equipment:

1. **Convection Toaster Oven:**

   - [BLACK+DECKER TO3250XSB 8-Slice Extra Wide Convection Countertop Toaster Oven](https://www.amazon.com/BLACK-DECKER-TO3250XSB-Convection-Countertop/dp/B00LU2I428)
     - Ensure it has a fan inside for more even heating.
     - Never use this oven for food.

2. **Thermocouple Thermometer:**

   - [Digital Thermocouple Temperature Thermometer, PEAKMETER PM6501](https://www.amazon.com/Thermocouple-Temperature-Thermometer-PEAKMETER-Fahrenheit/dp/B08L11MMFM)
     - Make sure the probe and probe jacket can go up to ~300°C.

3. **Solder Paste:**

   - [Chip Quik SMD291AX50T3 Solder Paste in jar 50g (T3) Sn63/Pb37 no clean](https://www.amazon.com/gp/product/B07BH5LP5G)
     - Keep it in the refrigerator for optimal stenciling results.
     - Wash hands well after handling.

4. **Tweezers:**

   - [Aven 18072ARS 7-SA Style Artis Tweezer](https://www.amazon.com/Aven-18072ARS-Style-Tweezer-Yellow/dp/B01D4R1OXW)
     - Curved Aven Technik 7-SA Tweezers for placing parts.

5. **Magnifier Headset:**
   - [Headband Magnifier Hands-Free Jeweler Loupe Head Mount Magnifying Headset Visor](https://www.amazon.com/Headband-Magnifier-Jeweler-Magnifying-Replaceable/dp/B08RYVH7DL)
     - Dorky but effective, especially for small components.

## Soldering Process:

1. **Stencil and Paste:**

   - Use Sn63/Pb37 solder paste.
   - Keep paste in the refrigerator before stenciling.
   - Take your time to stencil correctly. Wipe off excess paste with IPA if needed.

2. **Component Placement:**

   - Use tweezers to place components on the pasted board.
   - Consider using a magnifier headset for precision.

3. **Reflow Process:**

   - Place the board(s) on the wire rack inside the toaster oven.
   - Insert the thermocouple inside, ensuring it holds above the PCB.
   - Turn on convection bake, medium setting.
   - Soak Phase (140-150°C for 2 minutes): Maintain even temperature.
   - Reflow Phase (200-220°C for 30 seconds): Watch for paste melting.
   - Turn off the toaster oven and open the door.

4. **Cooling and Inspection:**

   - Let the boards cool with the oven door open.
   - Once cool, inspect with a microscope for dry pads or bridges.
   - Repair using paste flux, solder braid, and a soldering iron if necessary.

5. **Double-Sided Boards:**
   - If parts are on both sides, repeat the process for the second side.
   - Use a metal stand to keep bottom-side parts off the wire rack.

Happy soldering!

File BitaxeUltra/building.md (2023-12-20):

# Building PCBs

In order to get PCBs made, you usually need to provide them with the following files;

- Gerbers
- Drill Files

Additionally if you want to have a shop assemble the boards for you, you’ll also need to provide;

- Bill of Materials (BOM)
- Centroid file (XY)

### Generating Gerbers and Drill Files

Gerbers are a set of files in a standard format that allow a PCB manufacturer to build the PCB. Usually there is one gerber file for each layer of a PCB. A Gerber file can represent a wide variety of different layer types;

- Copper layer
- Silkscreen Layer
- Soldermask layer
- Board outline
- Drills (Okay, this is actually not a gerber, but your PCB house will definitely need it)

Any* PCB CAD software will allow you to generate gerbers. We use [KiCad](https://www.kicad.org) because it is open source, free, and *awesome\*. Here is how to generate gerbers in KiCad v6;

1. Open up the design in KiCad and switch to the PCB board editor view (ie not the schematic). Some people call this pcbnew.
2. Choose File → Fabrication Outputs → Gerbers (.gbr)…
3. Pick the right options for what your PCB board house expects. Here is what I use;

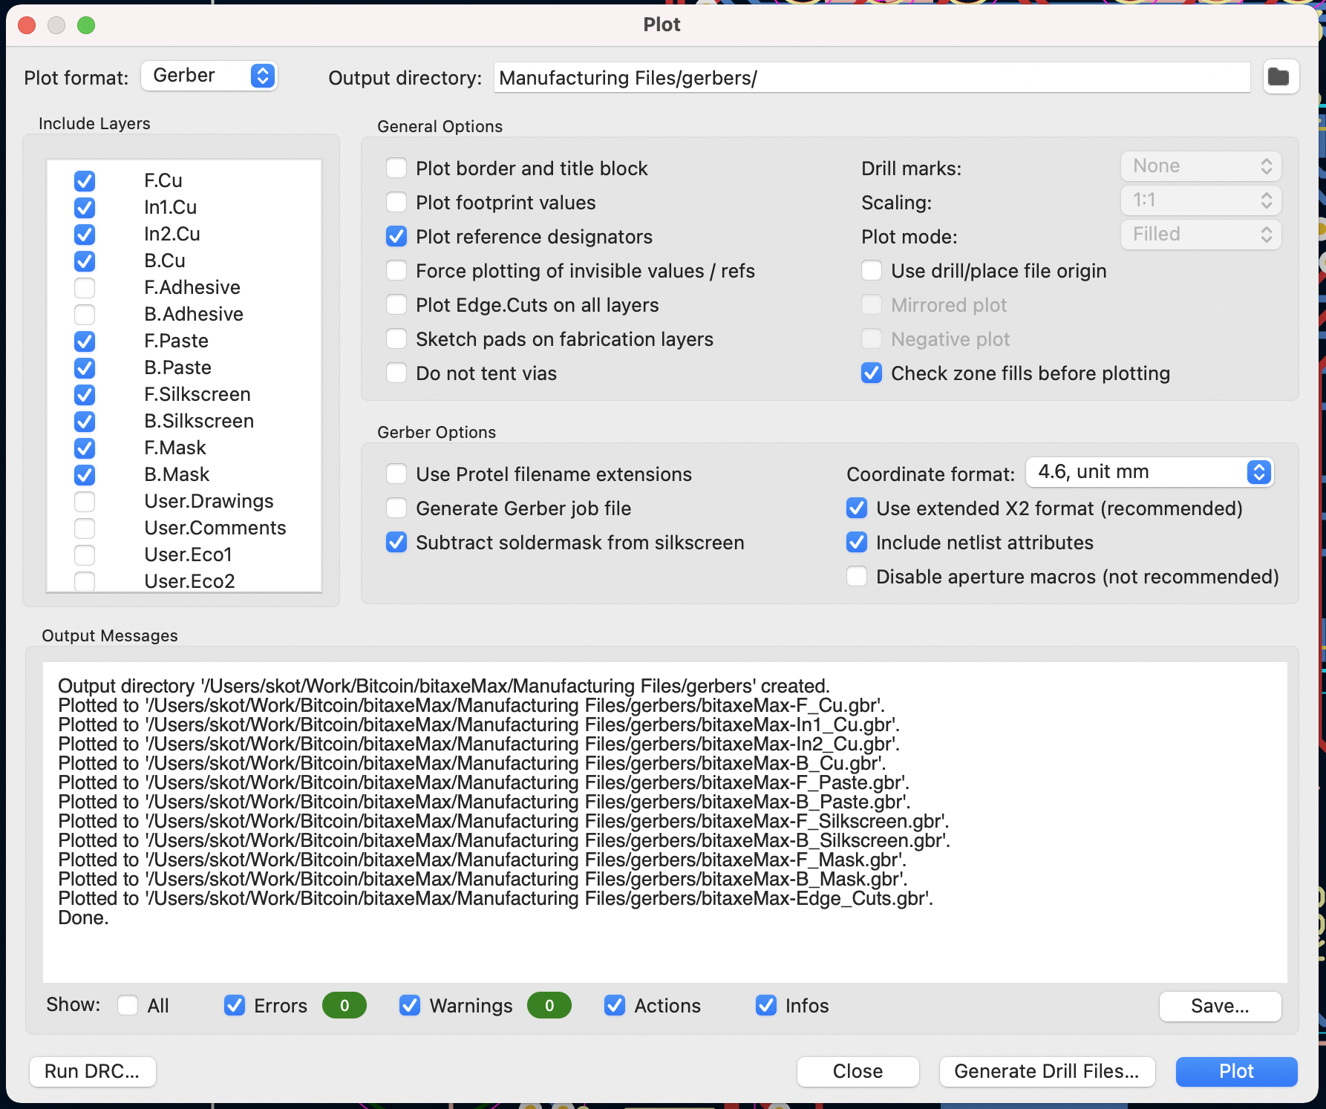
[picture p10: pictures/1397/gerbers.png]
Gerber Plot Window


Make sure you have these “Include Layers” checked;

- **F.Cu** → Front copper
- **In1.Cu** → Inner layer 1 Copper
- **In2.Cu** → Inner layer 2 Copper
- **B.Cu** → Back copper
- **F.Paste** → Front Paste. Note: this is used to make a solder paste stencil. This is optional. Many PCB houses will let you order stencils as a separate step. use these gerbers for ordering a stencil
- **B.Paste** → Back paste. see note above
- **F.Silkscreen** → Front Silkscreen. sometimes this is called the Legend
- **B.Silkscreen** → Back Silkscreen. sometimes this is called the Legend of Zelda
- **F.Mask** → Front soldermask
- **B.Mask** → Back soldermask
- **Edge.Cuts** → The board outline. This defines the shape the PCB is cut to.

1. Next you’ll want to generate the drill files. Click that button in the lower right corner of the “Plot” screen from above.
2. Generate the drill files according to your PCB house specs. Here are the options I use;

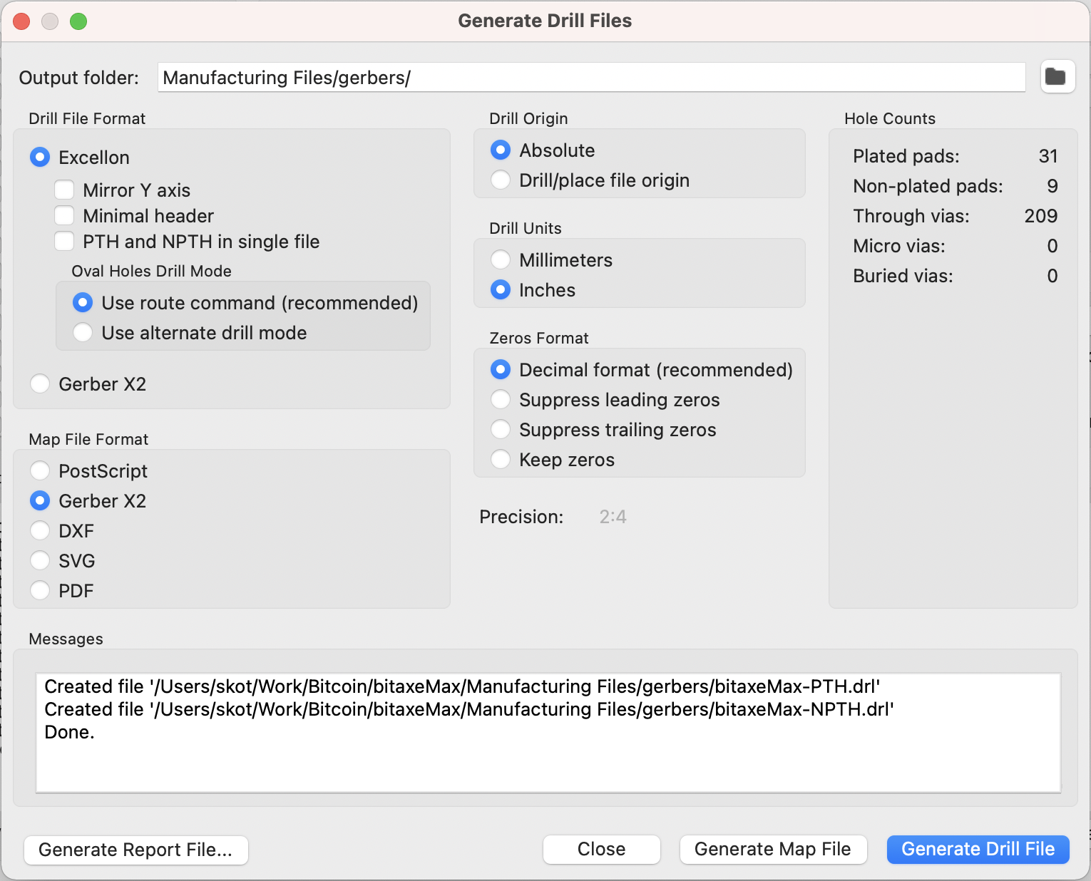
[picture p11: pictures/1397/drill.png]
Drill Files Window


That’s it! Take all of those generated files and give them to your PCB house. If you’re ordering stencils (which you should!), pull out `-F_Paste.gbr` and `-B_Paste.gbr` and send those to the right place. Paste gerbers are not needed to manufacture a PCB.

### Generating PCBA Manufacturing files

- TBD

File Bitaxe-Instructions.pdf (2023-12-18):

# Bitaxe-Setup-Instructions

### Requirements

- Power supply 5V 4-5A
- Purchase one from Amazon

### Quick Setup steps:

1. Power On: Connect the Bitaxe to the power supply. Once powered on, the Bitaxe will create its own Wi-Fi network.
2. Connectto Bitaxe Wi-Fi: On your device connect to the Wi-Fi network created by the Bitaxe
3. Access Bitaxe Config Page: Open a web browser and enter 192.168.4.1 in the address bar. This will take you to the Bitaxe configuration page.
4. Change Settings Navigate to the “Settings” tab on the Bitaxe website. Change the Wi-Fi SSID and password aswell as you btc address in here. Keep the pool if you want to solo mine to it (it’s free)
5. When you save these settings you have to restart the Bitaxe, click on the restart button. Now wait for your Bitaxe to show it’s new IP address on it’s little screen to enter again into the WebUI
6. Happy Hashing.

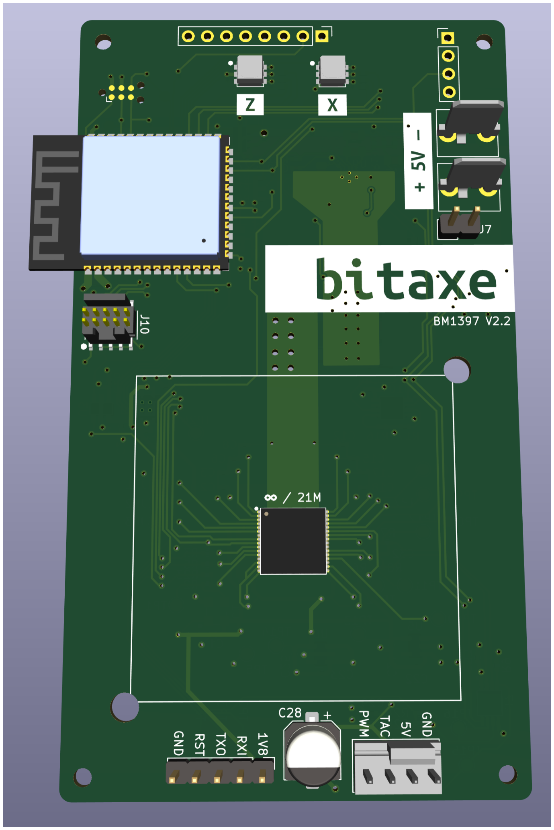
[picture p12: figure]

# Step 1 Connect Power

### Setup steps:

Grab the Power Supply
included in your shipment
and connect it to the
Bitaxe.

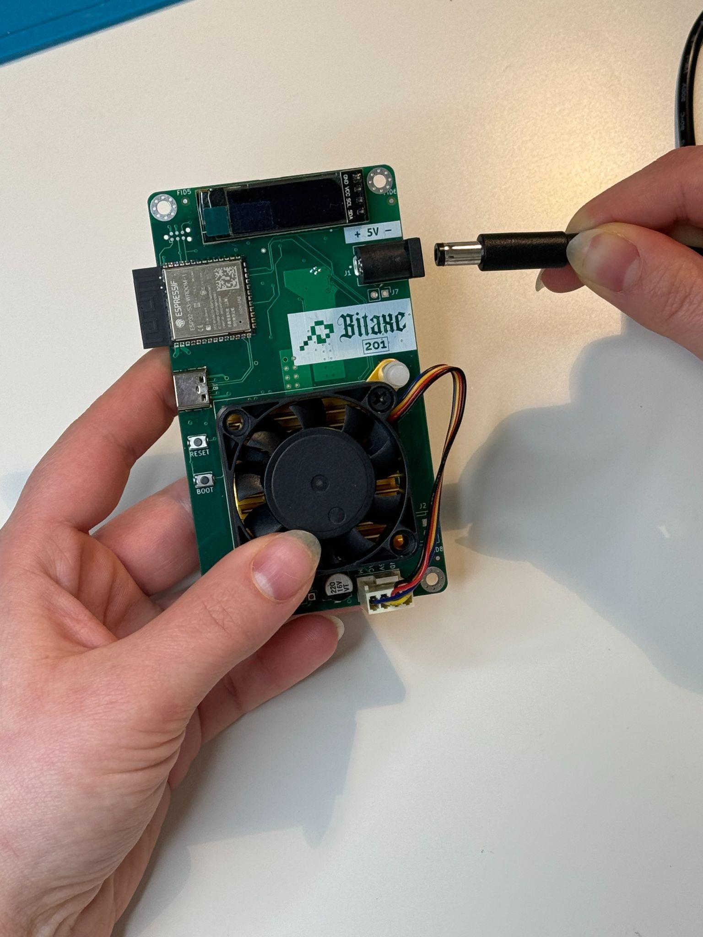
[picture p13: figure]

Make sure that
the Barrel Plug
is all the way in
and has a proper
connection with
the Connector

# Step 2 Connect to

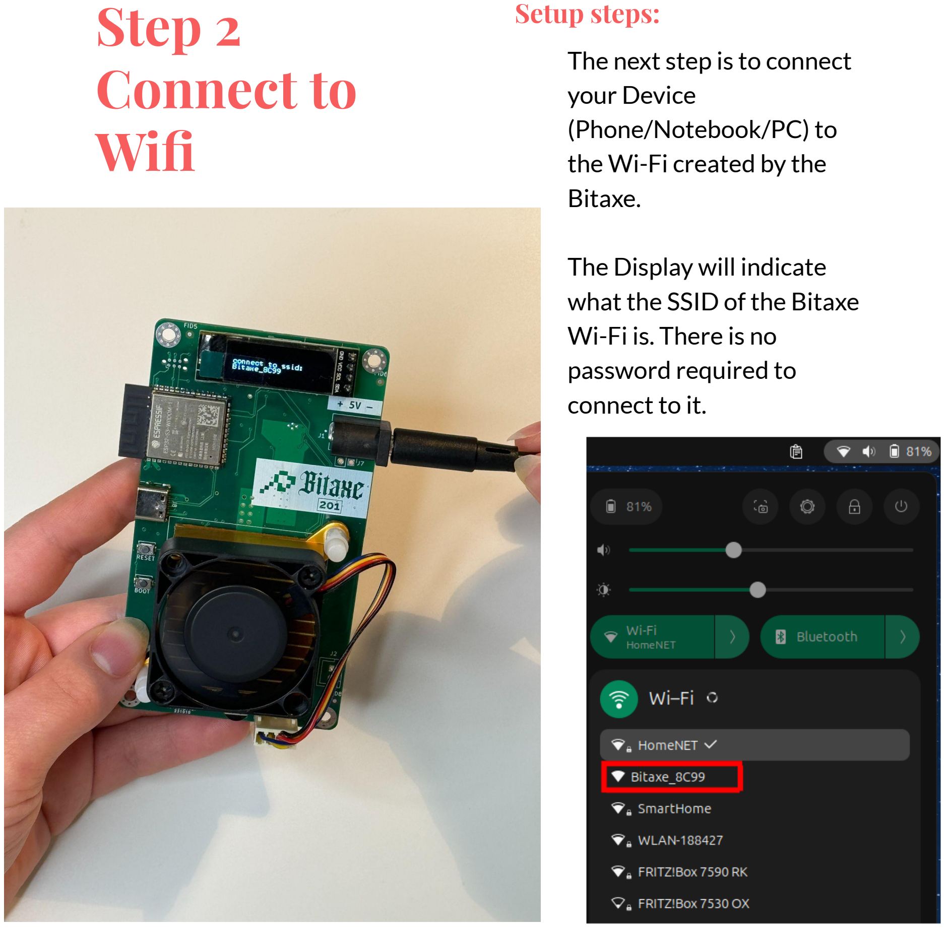
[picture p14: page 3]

# Wifi

### Setup steps:

The next step is to connect your Device
(Phone/Notebook/PC) to
the Wi-Fi created by the
Bitaxe.

The Display will indicate
what the SSID of the Bitaxe Wi-Fi is. There is no
password required to
connect to it.

# Step 3 Setup process

### Setup steps:

When connected with the
Bitaxe Wi-Fi it should
automatically open a new
Browser Tab for you. If not open the Browser and
navigate to the following
website: 192.168.4.1

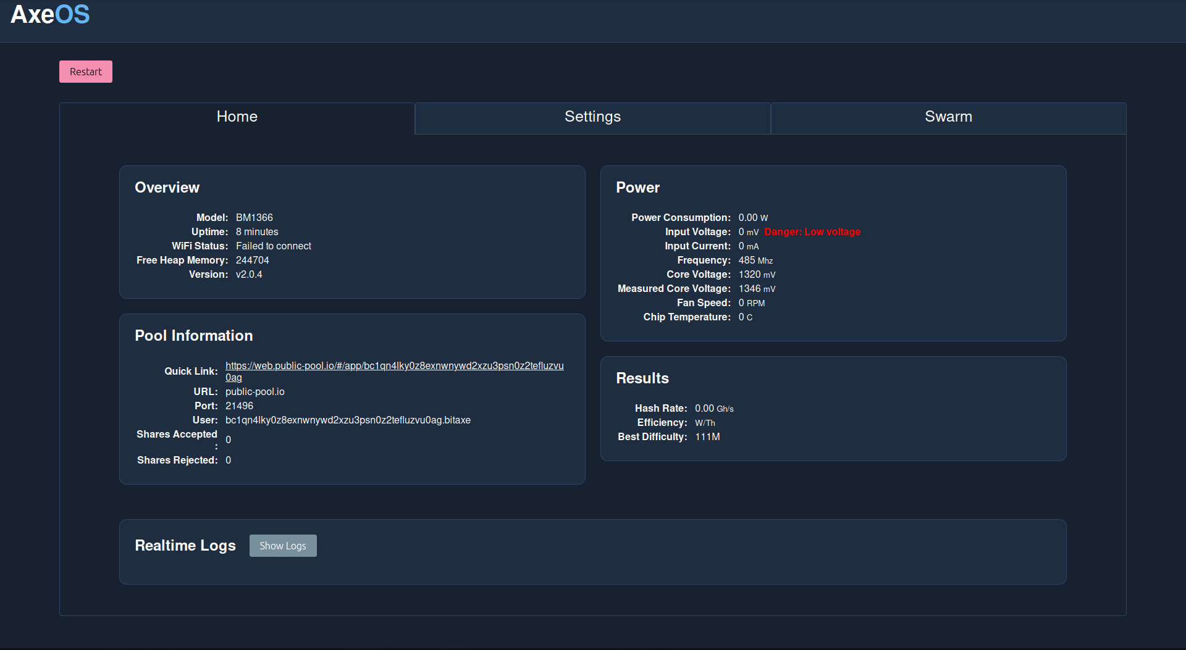
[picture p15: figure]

# Step 4 Configure on WebUI

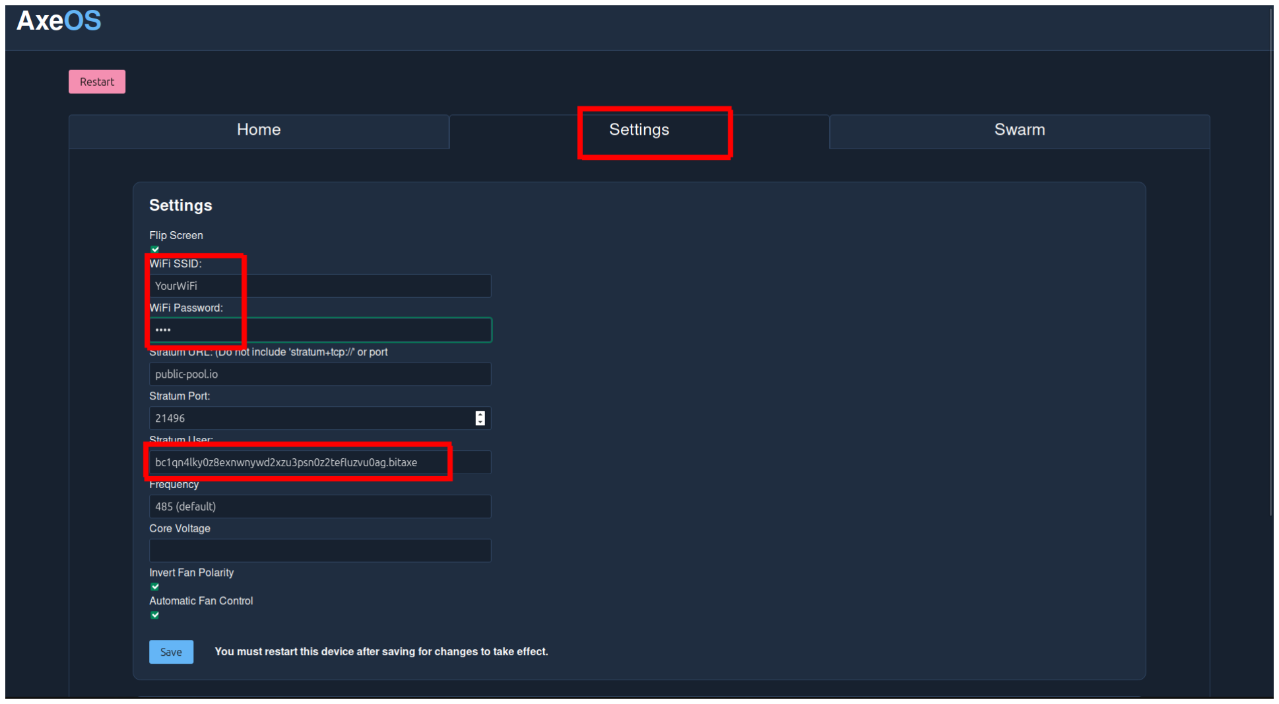
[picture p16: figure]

After changing your Settings, click on “Save” and then Restart the Bitaxe

### Setup steps:

Switch over to the Settings Tab and change your Wi-Fi
and your Wi-Fi password
as well as the BTC address to mine to your address

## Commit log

2023-12-20 assembly and building
2023-12-20 Max schematics
2023-12-20 update assembly and build
2023-12-21 MAX update
    [bitaxeMax BOM.xlsx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]
2023-12-22 Ultra init
    [bitaxeUltra BOM.xlsx]
2023-12-23 stencil holder
    [stencil_tool_V3.stl]
